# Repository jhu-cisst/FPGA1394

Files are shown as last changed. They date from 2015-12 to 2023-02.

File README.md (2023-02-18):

# FPGA1394
Design files for FPGA1394 board (FPGA + FireWire), Rev 1.x and 2.x, in Altium Designer format.
The design files for Rev 3.x are in [this repository](https://github.com/jhu-cisst/FPGA1394V3).

* `FPGA.PrjPCB`: Altium Designer project file
* `Snn.SchDoc`: schematics (Altium Designer format)
* `FPGA.PcbDoc`: PCB layout (Altium Designer format)
* `FPGA-Schematics.pdf`: PDF of schematics
* `FPGA-BOM.xls`: Bill of Materials (Microsoft Excel format)
* `FPGA1394-PCB-Fabrication.zip`: PCB fabrication (Gerber) files
* `FPGA1394-Assembly.zip`: PCB assembly files (e.g., paste masks, pick-and-place)
 
## Release Notes
 
* Rev 1.0/1.1 (PCB silkscreen is 1.0): Build #0 (5 board pilot run), Build #1 (44 boards)
* Rev 1.2: Build #2 (68 boards), Build #3 (72 boards)
  * Added J10 jumper on power input from IEEE-1394 (jumper OFF -> no power from IEEE-1394)
  * Changed J9 from 4-pin 2 mm header to 5-pin 0.1" header; pin 5 is connected to GND
  * Did not populate U12 (29.4989 MHz oscillator); use FPGA PLL to generate this frequency
* Rev 1.3: Build #4 (80 boards)
  * Added protection diodes (D10-D17), shunt regulator (U12), and supporting components to FireWire signal lines
  * Enable off-board 5V and 3.3V power (via U4 and U5) after local 5V power is good (determined by U9)
  * Added holes/pads on PCB traces for 5V, 3.3V, and 1.2V power supplies to facilitate troubleshooting
  * Removed 29.4989 MHz oscillator (U12) and supporting components from PCB and BOM (was "Do Not Install")
  * Modified U2 footprint to accommodate all variants of SO-8 package
  * Changed internal layers from 2 oz to 1 oz copper
* Rev 2.0: Prototype build (3 boards)
  * Added 10BASE-T/100BASE-TX Ethernet port using Micrel KSZ8851-16MLL MAC/PHY chip.
  * Redesigned DC/DC power supplies (5V, 3.3V, and 1.2V) to provide higher output currents.
  * Removed USB Mini connector (J6) and associated USB to UART bridge chip (CP2103). It is still possible to obtain a USB interface by connecting an appropriate TTL to USB Serial Converter Cable to header J9.
  * Removed jumper (J10) that allowed board to obtain power from IEEE-1394 cable (this feature was never used). Also removed power passthrough between IEEE-1394 connectors.
  * Removed diode isolation between power supply connectors J5 and J7; power should be connected to only one of these.
  * Changed FPGA oscillator from 40 MHz (pin AB12) to 25 MHz (pin M3).
  * Changes to the I/O pin connections on the FPGA (see schematic).
* Rev 2.1: Build #5 (92 boards), Build #6 (75 boards), Build #7 (120 boards), Build #8 (80 boards)
  * Moved power connector (J5) to increase space for JTAG connector (J8).
  * Corrected connection of "ST" and "FPGA PROG" LEDs (were swapped in Rev 2.0).
  * Fixed one unconnected GND test point, moved voltage test points, and added one more GND test point.
  * Changes to facilitate board assembly: wider slot spacing for IEEE-1394 connector, notch on board edge for better seating of IEEE-1394 connector, changed pad size for L1-L3.
* Rev 3.x: See [this repository](https://github.com/jhu-cisst/FPGA1394V3)

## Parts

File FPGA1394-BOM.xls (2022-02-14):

 | IEEE-1394/Ethernet FPGA Board, Rev 2.1
 | Bill Of Materials
 | 2022-02-14
Revision: |  | 2.1
Seq | Qty. | Ref Des | Description | Package | Manufacturer | Notes | Manufacturer Part # | Distributor | Distributor Part # | Avcon Part # | Est. Unit $ | Extended Cost
1 | 3 | C1-3 | CAP 10pF, 5%, 50V, NPO, 0603 | 0603 | MuRata | 2 | GRM1885C1H100JA01D | Digikey | 490-1403-1-ND | 022-1006-61/603 | 0.04 | 0.12
2 | 2 | C4-5 | CAP, 220pF, 5%, 50V, NPO, 0603 | 0603 | Kemet | 2 | C0603C221J5GACTU | Digikey | 399-1066-1-ND | 022-2216-61/603 | 0.02 | 0.05
3 | 1 | C6 | CAP, 1000pF, 5%, 50V, NPO, 0603 | 0603 | MuRata | 2 | GRM1885C1H102JA01D | Digikey | 490-1451-1-ND | 022-1026-61/603 | 0.03 | 0.03
4 | 3 | C7-9 | CAP 0.01uF, 10%, 50V, X7R, 0603 | 0603 | Kemet | 2 | C0603C103K5RACTU | Digikey | 399-1091-1-ND | 022-1036-71/603 | 0.04 | 0.13
5 | 4 | C10-13 | CAP, 0.1uF, 10%, 50V, X7R, 0603 | 0603 | MuRata | 2 | GCM188R71H104KA57D | Digikey | 490-4779-1-ND | 022-1046-71/603 | 0.04 | 0.14
6 | 5 | C14-18 | CAP, 1.0uF 10% 16V X7R, 0603 | 0603 | MuRata | 2, 8 | GRM188R71C105KA12D | Digikey | 490-3900-1-ND | 022-1052-71/603 | 0.05 | 0.24
7 | 5 | C19-23 | CAP, 10uF, 20%, 6.3V, X5R, 0603 | 0603 | MuRata | 2 | GRM188R60J106ME47D | Digikey | 490-3896-1-ND | 022-1060-81/603 | 0.01 | 0.03
8 | 2 | C24-25 | CAP, 10uF, 20%, 25V, X5R, 0805 | 0805 | MuRata | 2 | GRM21BR61E106KA73L | Digikey | 490-5523-1-ND | 022-1064-71/805 | 0.10 | 0.20
9 | 4 | C26-29 | CAP, 100uF, 20%, 10V, X5R, 1210 | 1210 | Samsung | 2 | CL32A107MPVNNNE | Digikey | 1276-3364-1-ND | 022-1071-81/121 | 0.65 | 2.60
10 | 2 | C30-31 | CAP, 220uF, 20%, 6.3V, X5R, 1210 | 1210 | Samsung | 2 | CL32A227MQVNNNE | Digikey | 1276-3375-1-ND | 022-2270-81/121 | 1.22 | 2.44
11 | 2 | C32-33 | CAP, 680uF 20%, 2.5V, Conductive Polymer "KO Cap" | CAP-D | Kemet | NS | T520D687M2R5ATE015 | Digikey | 399-4065-1-ND | 022-6870-81SMD | 1.31 | 2.62
12 | 2 | C34-35 | CAP, 470uF 20%, 6.3V, Conductive Polymer "KO Cap" | CAP-D | Kemet | NS, 9 | T520D477M006ATE025 | Digikey | 399-4985-1-ND | 022-4770-71SMD | 3.90 | 7.80
13 | 3 | C36-38 | CAP, 330uF 20%, 10V, Conductive Polymer "KO Cap" | CAP-D | Kemet | NS | T520Y337M010ATE015 (x=T or H) | Digikey | 399-10362-1-ND | 022-3371-81SM | 2.29 | 6.87
14 | 3 | C39-41 | CAP, 33uF 20%, 50V, Conductive Polymer "KO Cap" | CAP-D | Kemet | NS | T521X336M050ATE075 | Digikey | 399-11721-1-ND | 022-3366-81SM | 4.80 | 14.40
15 | 62 | C101-162 | CAP, 0.1uF, 10% 16V, X7R, 0402 | 0402 | MuRata | 2 | GRM155R71C104KA88D | Digikey | 490-3261-1-ND | 022-1042-71/402 | 0.00489 | 0.30
16 | 6 | CN1-6 | CAP Array, 4x 0.1uF, 10%, 16V, X7R | 0805 | AVX | 2, 6 | W2A4YC104KAT2A | Digikey | 478-11155-1-ND | 022-1040-81/805 | 0.28 | 1.69
17 | 1 | D1 | TVS, 28V, Unidirectional, 1500W, SMCJ28A | DIODE-SMC | Littlefuse | 2 | SMCJ28ALFCT-ND | Digikey | SMCJ28ALFCT-ND | 024-0949-SM | 0.46 | 0.46
18 | 1 | D2 | DIODE, Zener, 10V, MMSZ5240 | SOD-323 | Vishay |  | MMSZ5240BS-7-F | Digikey | MMSZ5240BS-FDICT-ND | 024-0309-SM | 0.19 | 0.19
19 | 5 | D3-7 | LED, Green, RA, 0805 | 0805 | Osram |  | LG R971-KN-1 | Digikey | 475-1410-1-ND | 024-6176-805 | 0.06 | 0.30
20 | 8 | D8-15 | DIODE, BAV99T, Dual/Serial, 70V, 85mA | SOT-523 | Diodes Inc. |  | BAV99T-7-F | Digikey | BAV99T-FDICT-ND | 024-0118-SM | 0.04 | 0.34
21 | 2 | J1-2 | CONN, Socket, 2x22 Pos, Vertical, 2MM | TH | Samtec |  | ESQT-122-02-L-D-560 | Samtec | ESQT-122-02-L-D-560 | 026-0844-00 | 5.72 | 11.44
22 | 2 | J3-4 | CONN, IEEE-1394, 6-Pin, R/A | Firewire6-RA | 3M | NS, 10 | 3E106-2230KV | Digikey | 3M9423-ND | 026-1139-00 | 3.34 | 6.69
23 | 1 | J5 | CONN, Power Jack, 2.1mm, RA | TH | Switchcraft | 2 | RAPC722X | Digikey | SC1313-ND | 026-0383-00 | 0.87 | 0.87
24 | 1 | J6 | CONN, RJ-45 with Ethernet Transformer | RJ-45 | Pulse |  | J00-0045NL | Digikey | 553-1619-5-ND | 026-0690-00 | 4.49 | 4.49
25 | 1 | J7 | CONN, Header, 2 Pos, Vertical 0.100 | TH | Tyco | 2 | 640456-2 | Digikey | A1921-ND | 026-0080-00 | 0.09 | 0.09
26 | 1 | J8 | CONN, Header, 2x7 Pos, Vertical, Polarized, 2MM | TH | FCI |  | 98414-G06-14LF | Digikey | 609-2576-ND | 026-0847-00 | 1.74 | 1.74
27 | 1 | J9 | CONN, Header, 6 Pos, Vert 0.1" pitch, 0.23" - 0.318" ht | TH | Generic | 2 | 5-146280-6, TSW-106-07-L-S | Digikey | A121372-ND | 029-0507-06 | 0.45 | 0.45
28 | 1 | L1 | INDUCTOR, 4.7uH, 15A, XAL7070 | XAL7070 | Coilcraft | NS | XAL7070-472MEx (x=B or C) | Coilcraft | XAL7070-472MEB | 023-0381-SM | 3.14 | 3.14
29 | 2 | L2-3 | INDUCTOR, 3.3uH, 5.5A, XAL4030 | XAL4030 | Coilcraft | NS | XAL4030-332MEx (x=B or C) | Coilcraft | XAL4030-332MEB | 023-0372-SM | 1.80 | 3.60
30 | 3 | L4-6 | FERRITE BEAD, 50 Ohm/10 mOhm, 6A | 1206 | Laird | 2 | HI1206T500R-10 | Digikey | 240-2412-1-ND | 023-0431-1206 | 0.06 | 0.17
31 | 4 | L7-10 | INDUCTOR, 1uH, 600mA, 200mOhm | 0603 | Kemet | 2 | L0603B1R0MPWFT | Digikey | 399-9562-1-ND | 023-0432-603 | 0.22 | 0.87
32 | 2 | Q1-2 | MOSFET, N-Chan, 20V, Si7108 | PowerPack-1212 | Vishay |  | SI7108DN-T1-GE3 | Digikey | SI7108DN-T1-GE3CT-ND | 024-2189-SM | 1.31 | 2.62
33 | 1 | Q3 | MOSFET, P-Chan, 40V, Si7611 | PowerPack-1212 | Vishay | 4 | SI7611DN-T1-GE3 | Digikey | SI7611DN-T1-GE3CT-ND | 024-2193-SM | 0.70 | 0.70
34 | 3 | Q4-6 | MOSFET, Dual N-Chan, 30V, PMGD175XN | SOT-363 | ON Semi | 2, 7 | NTJD4001NT1G | Digikey | NTJD4001NT1GOSCT-ND | 024-2190-SM | 0.43 | 1.29
35 | 1 | Q7 | TRANSISTOR, PNP, 1A, 20V, DCX69-16 | SOT-89 | NXP | 5 | BC869-16,115 | Digikey | 1727-2363-1-ND | 024-1036-SM | 0.35 | 0.35
36 | 8 | R1-8 | RES, 56.0, 0.5%, 1/10W, 0603 | 0603 | Susumu | 2 | RR0816Q-560-D | Digikey | RR08Q56DCT-ND | 020-5607-41/603 | 0.02 | 0.19
37 | 4 | R9-12 | RES, 4.99K, 1%, 1/10W, 0603 | 0603 | Generic | 2 | ERJ-3EKF4991V |  |  | 020-4991-51/603 | 0.03 | 0.10
38 | 1 | R13 | RES, 6.34K, 1%, 1/10W, 0603 | 0603 | Generic | 2 | RC0603FR-076K34L |  |  | 020-6341-51/603 | 0.02 | 0.02
39 | 5 | R14-18 | RES, 499, 1%, 1/10W, 0603 | 0603 | Generic | 2 | CRCW0603499RDHEAP (0.5%) |  |  | 020-4990-51/603 | 0.09 | 0.45
40 | 2 | R19-20 | RES, 100, 1%, 1/10W, 0603 | 0603 | Generic | 2 | RK73H1JTTD1000F |  |  | 020-1000-51/603 | 0.01 | 0.02
41 | 2 | R21-22 | RES, 200, 1%, 1/10W, 0603 | 0603 | Generic | 2 | RMCF0603FT200R |  |  | 020-2000-51/603 | 0.01 | 0.01
42 | 2 | R23-24 | RES, 1.00K, 1%, 1/10W, 0603 | 0603 | Generic | 2 | RC0603FR-071KL |  |  | 020-1001-51/603 | 0.01 | 0.02
43 | 1 | R25 | RES, 20.0K, 1%, 1/10W, 0603 | 0603 | Generic | 2 | RC0603FR-0720KL |  |  | 020-2002-51/603 | 0.02 | 0.02
44 | 1 | R26 | RES, 31.6K, 1%, 1/10W, 0603 | 0603 | Generic | 2 | ERJ-3EKF3162V |  |  | 020-3162-51/603 | 0.03 | 0.03
45 | 2 | R27-28 | RES, 49.9K, 1%, 1/10W, 0603 | 0603 | Generic | 2 | CRCW060349K9FKEA |  |  | 020-4992-51/603 | 0.06 | 0.11
46 | 1 | R29 | RES, 3.01K, 1%, 1/10W, 0603 | 0603 | Generic | 2 | CRCW06033K01FKEA |  |  | 020-3011-51/603 | 0.04 | 0.04
47 | 3 | R30-32 | RES, 15.0K, 1%, 1/10W, 0603 | 0603 | Generic | 2 | RC0603FR-0715KL |  |  | 020-1502-51/603 | 0.01 | 0.03
48 | 4 | R33-36 | RES, 133K, 1%, 1/10W, 0603 | 0603 | Generic | 2 | ERJ-3EKF1333V |  |  | 020-1333-51/603 | 0.002 | 0.01
49 | 2 | R37-38 | RES, 66.5K, 1%, 1/10W, 0603 | 0603 | Generic | 2 | ERJ-3EKF6652V |  |  | 020-6652-51/603 | 0.01 | 0.03
50 | 1 | R39 | RES, 69.8K, 1%, 1/10W, 0603 | 0603 | Generic | 2 | ERJ-3EKF6982V |  |  | 020-6982-51/603 | 0.03 | 0.03
51 | 5 | R40-44 | RES, 301K, 0.1%, 1/10W, 0603 | 0603 | Susumu | 2 | RG1608P-3013-B-T5 | Digikey | RG16P301KBCT-ND | 020-3013-21/603 | 0.14 | 0.69
52 | 1 | R45 | Do Not Install | 0603 | Generic |  |  |  |  |  |  | 0.00
53 | 6 | R46-51 | RES, 49.9, 1%, 1/16W, 0402 | 0402 | Generic | 2 | RC0402FR-0749R9L |  |  | 020-4999-51/402 | 0.01 | 0.04
54 | 1 | R52 | RES, 0.050, 1%, 1/2W, 1206 | 1206 | Stackpole | 2 | CSR1206FK50L0 | Digikey | CSR1206FK50L0CT-ND | 020-5007-54SM | 0.23 | 0.23
55 | 1 | R53 | RES, 0.025, 1%, 1/2W, 1206 | 1206 | Stackpole | 2 | CSR1206FK25L0 | Digikey | CSR1206FK25L0CT-ND | 020-2507-54SM | 0.23 | 0.23
56 | 5 | RN1-5 | RES ARRAY, 4.7K, 4 DIS, 5%, SM 0.032 | R-SM-8/32 | CTS | 2 | 742C083472JP | Digikey | 742C083472JPCT-ND | 020-4701-61RA | 0.06 | 0.30
57 | 1 | RN6 | RES ARRAY, 220, 4 DIS, 5%, SM 0.032 | R-SM-8/32 | CTS | 2 | 742C083221JP | Digikey | 742C083221JPCT-ND | 020-2200-61RASM | 0.23 | 0.23
58 | 1 | SW1 | SWITCH, Rotary, Hex | TH | Grayhill | 2 | 94HAB16T | Digikey | GH7255-ND | 029-0458-00 | 2.48 | 2.48
59 | 1 | U1 | IC, FPGA, Spartan 6, XC6SLX45-FG484 | FG-484 | Xilinx | NS | XC6SLX45-2FGG484C | Digikey | 122-1674-ND | 024-9308-SM | 29.25 | 29.25
60 | 1 | U2 | IC, Serial Flash PROM, 16MBit, M25P16 | SO-8 | Numonyx |  | M25P16-VMN6P | Digikey | M25P16-VMN6P-ND | 024-4182-SM | 1.15 | 1.15
61 | 1 | U3 | IC, IEEE-1394 Physical Layer, TSB41AB2 | PQFP-65 | TI | NS | TSB41AB2PAP | Digikey | 296-11076-ND | 024-9309-SM | 5.55 | 5.55
62 | 1 | U4 | IC, Ethernet MAC/PHY Controller, KSZ8851 | QFP-48-7MM | Micrel | NS | KSZ8851-16MLL | Digikey | 576-3252-ND | 024-2751-SM | 4.28 | 4.28
63 | 2 | U5-6 | IC, MEMS Oscillator, 25.0 MHz | OSC-2x2.5mm | ECS, Inc. | 3 | ECS-2520MVQ-250-BP-TR | Digikey | 50-ECS-2520MVQ-250-BP-CT-ND | 024-9372-SM | 1.11 | 2.22
64 | 1 | U7 | IC, Oscillator, 24.576MHz, 50PPM, 3.3V | OSC-3x5MM | AVX | 2 | KC5032A24.5760CMxE00 | Digikey | 1253-1042-1-ND | 029-0459-SM | 1.31 | 1.31
65 | 2 | U8-9 | IC, Hot Swap Controller with retry, LTC4210-1 | SOT-23-6 | Linear Tech | 1 | LTC4210-1CS6#PBF | Linear Tech | LTC4210-1CS6#PBF | 024-3782-SM | 3.39 | 6.78
66 | 1 | U10 | IC, Step Down DC-DC, 42V, 6A, LT8612 | QFN-28-3x6mm | Linear Tech | 1 | LT8612EUDE#PBF | Linear Tech | LT8612EUDE#PBF | 024-2752-SM | 8.40 | 8.40
67 | 1 | U11 | IC, Dual DC-DC Converter, 3A/Chan, LTC3615 | QFN-24-4mm | Linear Tech | 1 | LTC3615EUF#PBF | Linear Tech | LTC3615EUF#PBF-ND | 024-2753-SM | 5.00 | 5.00
68 | 1 | U12 | IC, 4 Phase Spread Spectrum Clock, LTC6902 | MSOP-10 | Linear Tech | 1 | LTC6902CMS#TRPBFCT | Linear Tech | LTC6902CMS#TRPBF | 024-2754-SM | 4.28 | 4.28
69 | 1 | U13 | IC, Shunt Regulator, 1.24V, 70mA, TLVH431 | SC70-6 | TI |  | TLVH431ACDCK | Digikey | 296-32425-1 | 024-2415-SM | 0.68 | 0.68
70 | 1 |  | PCB, IEEE-1394/Ethernet FPGA Controller, Rev 2.1 |  |  |  |  |  |  |  | 7.60 | 7.60
 |  |  |  |  |  |  |  |  |  | Estimated Total Cost: |  | $161.27
Notes:
 | ● | Text highlighted in red is highlighted to draw attention to the value/parameter and does not carry any special meaning.
 | ● | Component prices shown are the best guess at the time of updating this BOM, assuming Qty ~100 boards. Actual prices may be higher or lower depending upon a number of factors.
 | ● | Unless specified otherwise, the only substitutions allowed are substituting identical part number parts from a different manufacturer.
 | NS | No substitutions of any kind are allowed.
 | 1 | For Linear Tech parts, it is acceptable to substitute I (industrial temp), E (extended temp) or H (high temp) rated parts.
 |  | The suffixes "TRM" and "TR" signify tape and reel styles. Parts with suffix TRM, suffix TR can be substituted as needed.
 |  | Other than as specified above, no other substitutions are allowed.
 | 2 | Any component in an identical package that meets or exceeds all the parameters specified in the description can be substituted.
 | 3 | Previously used Silicon Labs 501MAA-ADAG, which was ordered pre-programmed for 25.0MHz from Digikey, and then Abracon KC5032A24.5760CM0E00
 | 4 | An alternate part is SIS443DN (Digikey P/N SIS443DN-T1-GE3CT-ND)
 | 5 | Previously used DCX69-16-13 (Digikey P/N DCX69-16DICT-ND). Alternate part is higher-rated PNP 3A 25V (Digikey P/N FCX789ACT-ND)
 | 6 | Previously used TDK/Samsung CL21B104MOCNBNC (Digikey P/N 1276-2452-1-ND)
 | 7 | Previously used NXP PMGD175XNE (Digikey P/N 1727-2695-1-ND) and PMGD370XN (Digikey P/N 568-2367-1-ND). It is also possible to use NTJD4401NT1G, but note that it is a 20V part
 | 8 | It is acceptable to substitute an X5R capacitor, such as GRM188R61C105KA12D
 | 9 | Another approved part is Panasonic 6TPE470M
 | 10 | Another approved part is TE Connectivity AMP 5787956-1 (Digikey P/N A114040-ND)

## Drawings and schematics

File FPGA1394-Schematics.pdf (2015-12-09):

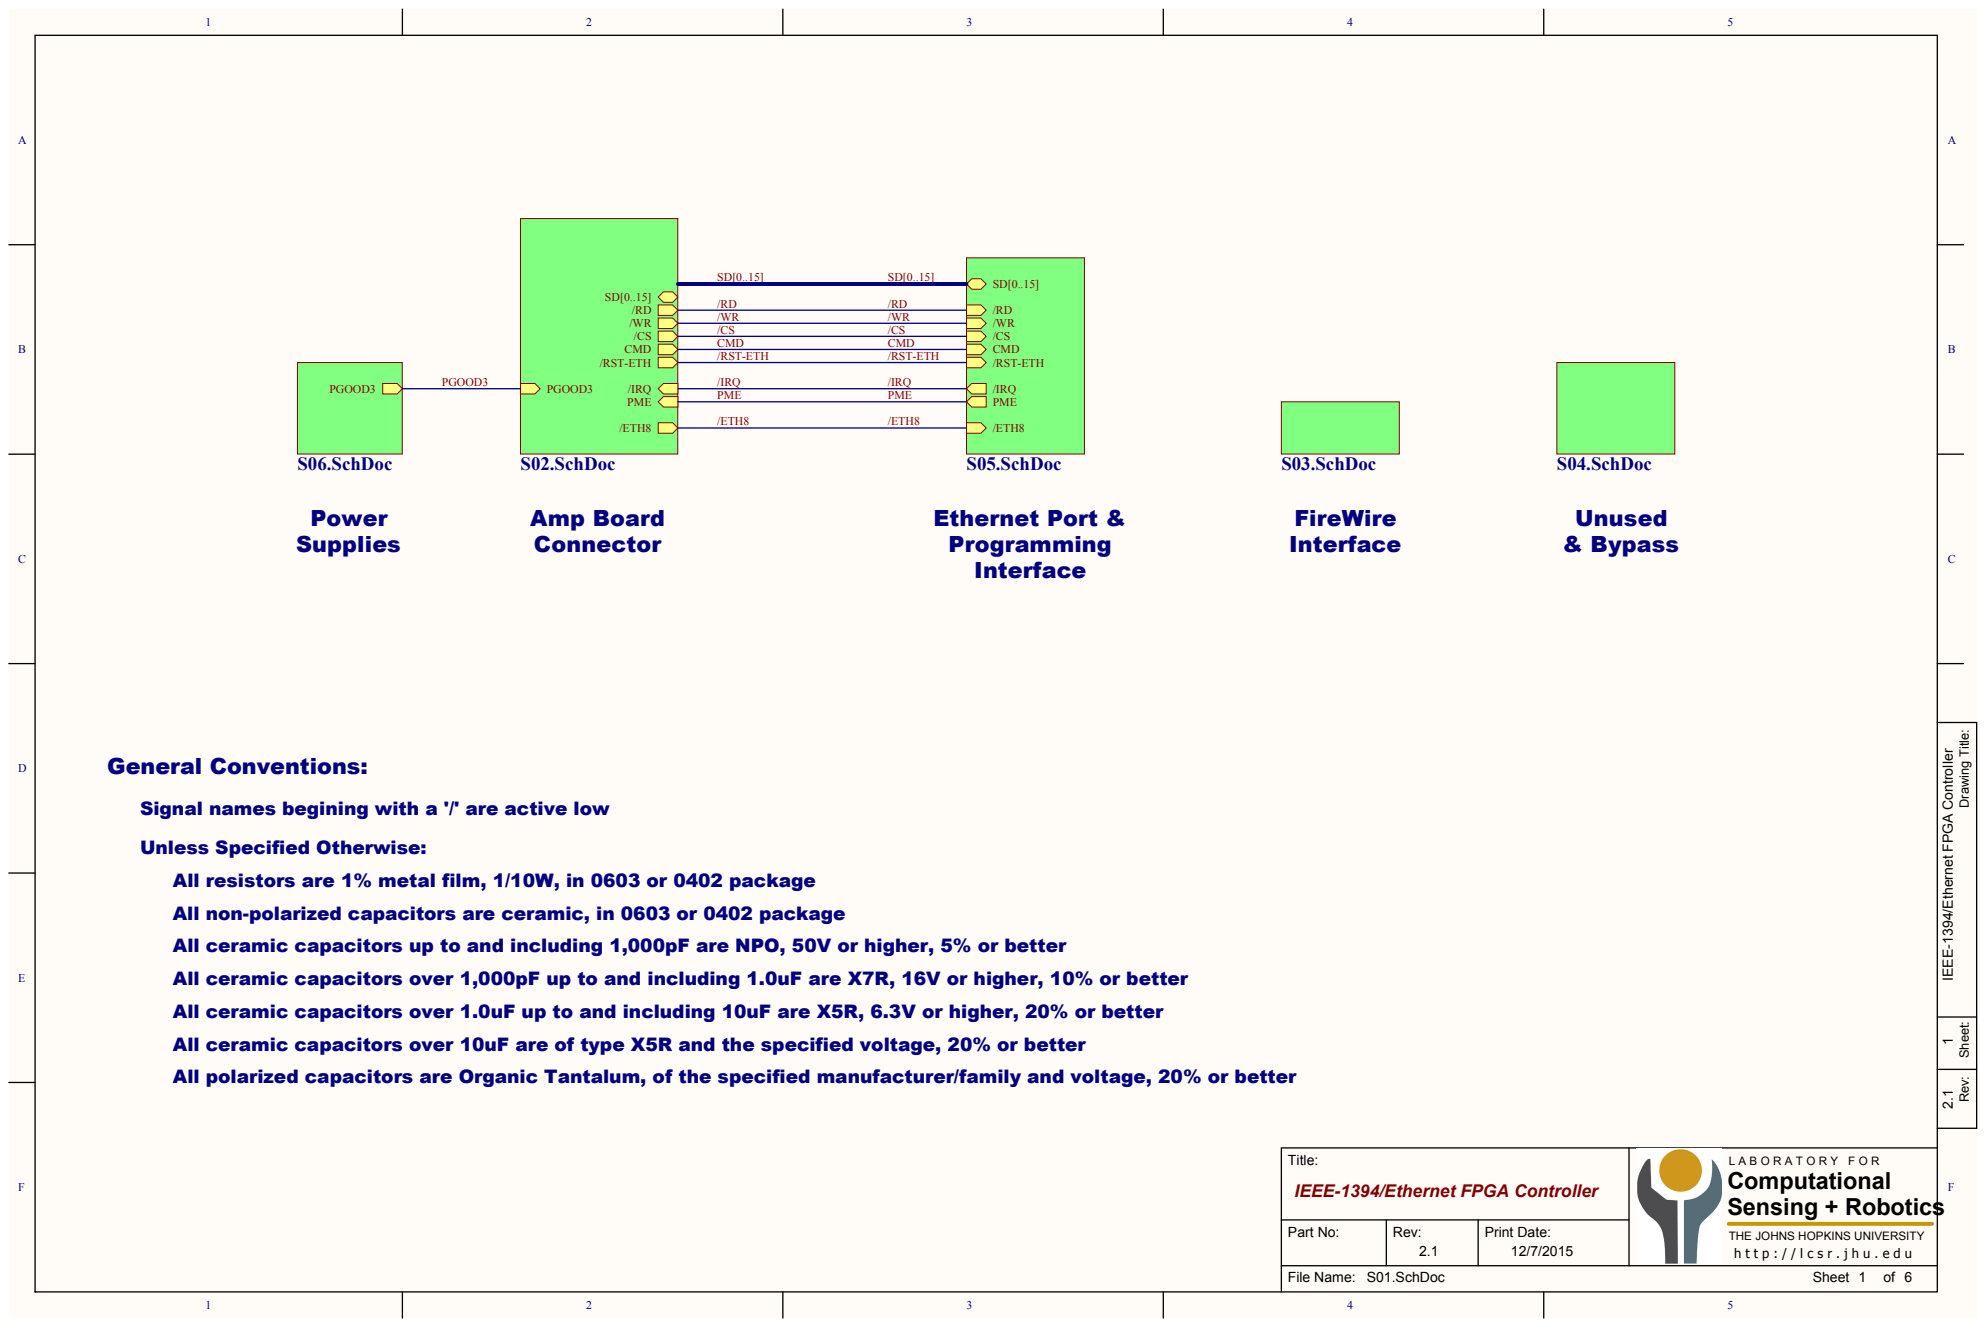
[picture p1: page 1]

Drawing Title: Rev: Sheet:

1 IEEE-1394/Ethernet FPGA Controller 2.1

Signal names begining with a '/' are active low

Unless Specified Otherwise:
All resistors are 1% metal film, 1/10W, in 0603 or 0402 package
All non-polarized capacitors are ceramic, in 0603 or 0402 package
All ceramic capacitors up to and including 1,000pF are NPO, 50V or higher, 5% or better
All ceramic capacitors over 1,000pF up to and including 1.0uF are X7R, 16V or higher, 10% or better
All ceramic capacitors over 1.0uF up to and including 10uF are X5R, 6.3V or higher, 20% or better
All ceramic capacitors over 10uF are of type X5R and the specified voltage, 20% or better
All polarized capacitors are Organic Tantalum, of the specified manufacturer/family and voltage, 20% or better

Title: IEEE-1394/Ethernet FPGA Controller | L A B O R A T O R Y F O R Computational THE JOHNS HOPKINS UNIVERSITY h t t p : / / l c s r . j h u . e d u

Part No: | Rev: 2.1 | Print Date: 12/7/2015

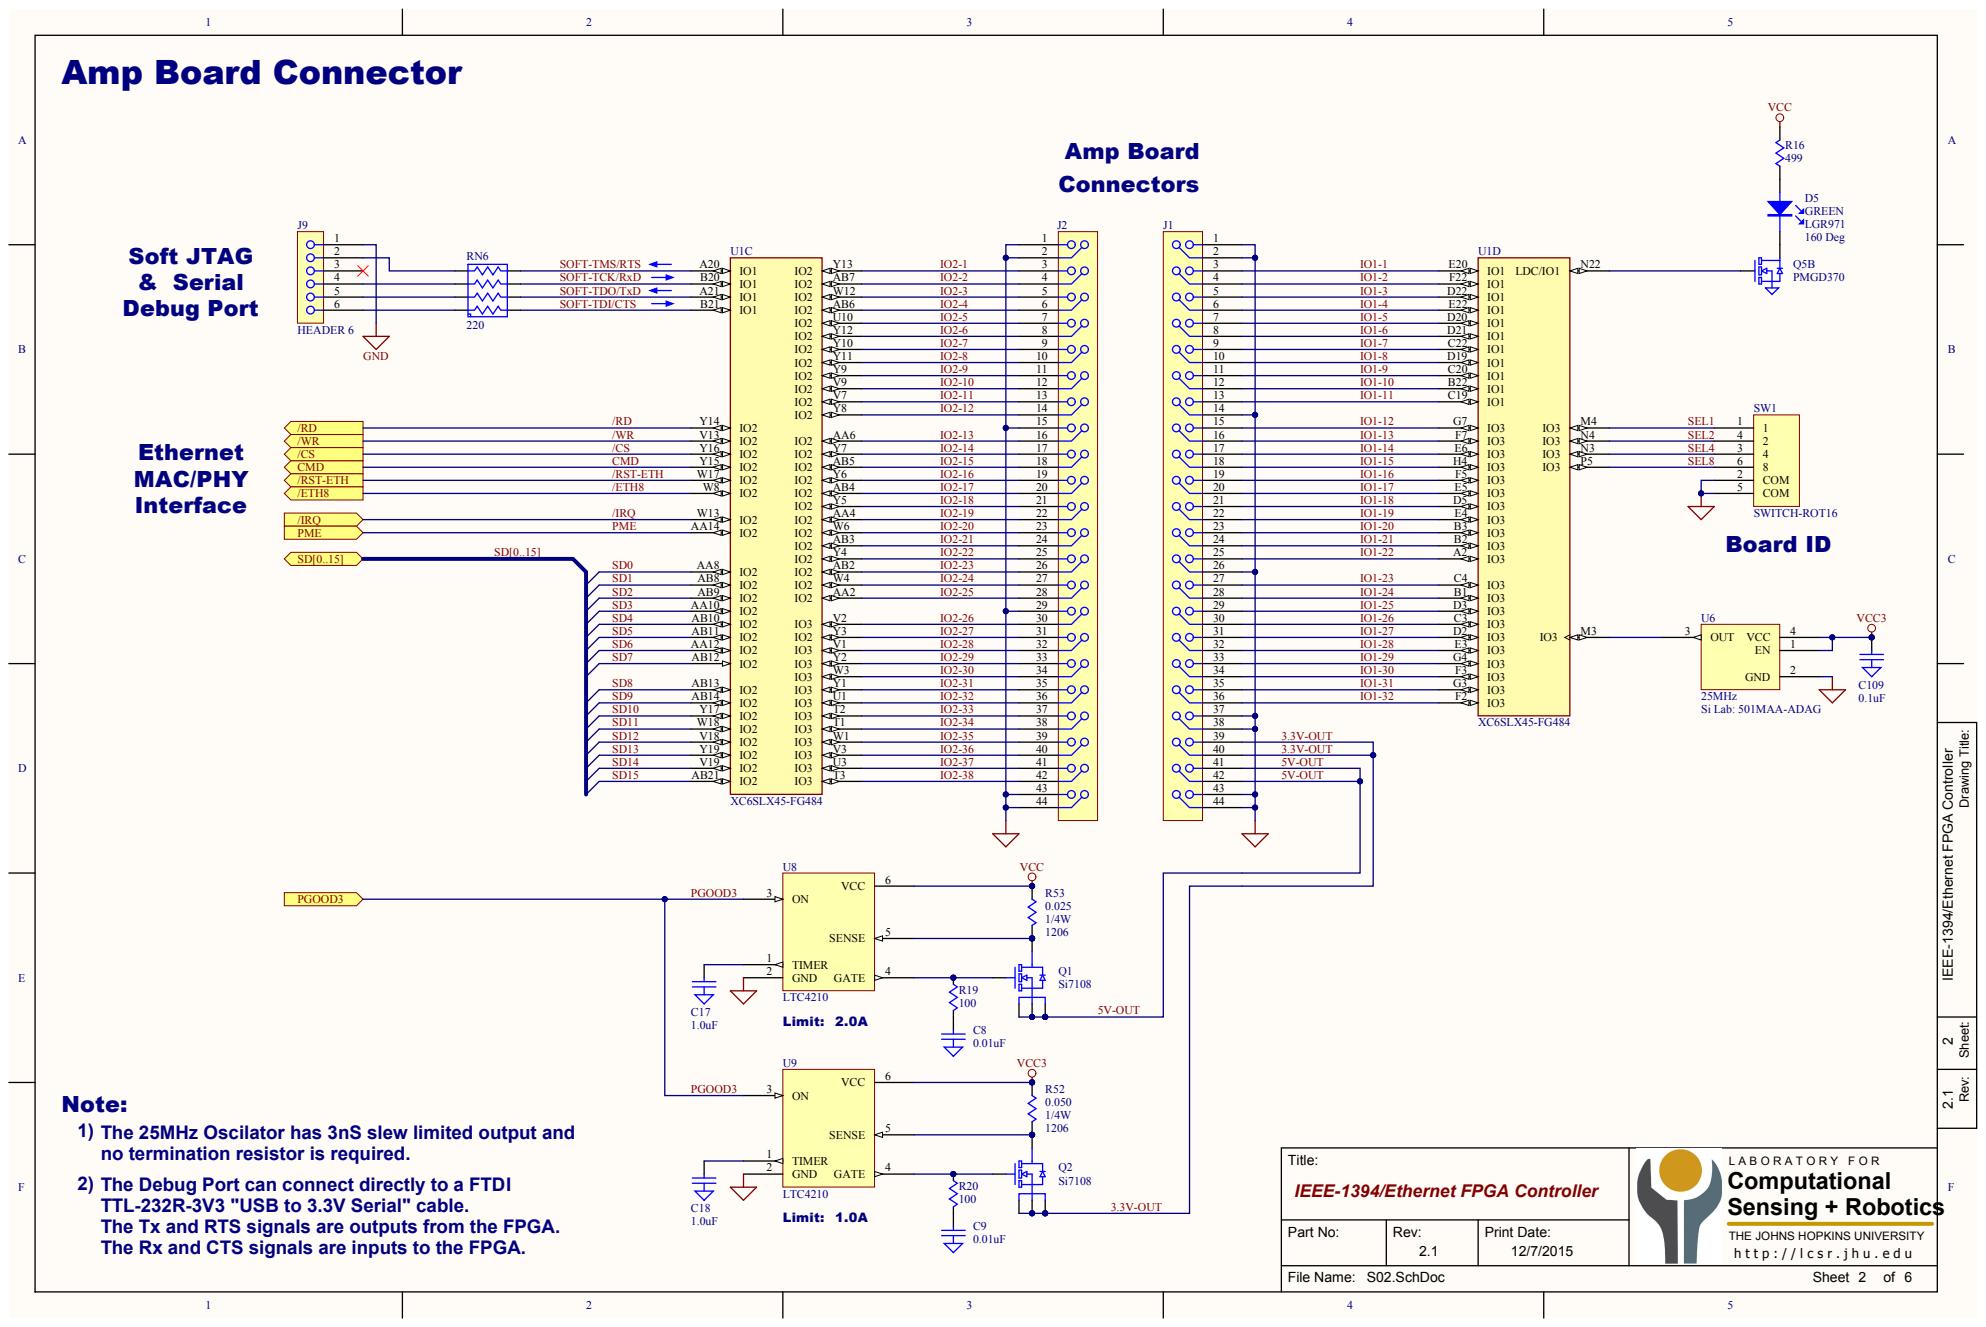
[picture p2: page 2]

Drawing Title: Rev: Sheet:

2 IEEE-1394/Ethernet FPGA Controller 2.1

Note: The 25MHz Oscilator has 3nS slew limited output and
no termination resistor is required.
The Debug Port can connect directly to a FTDI TTL-232R-3V3 "USB to 3.3V Serial" cable. The Tx and RTS signals are outputs from the FPGA

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

Part No: | Rev: 2.1 | Print Date: 12/7/2015

The Rx and CTS signals are inputs to the FPGA

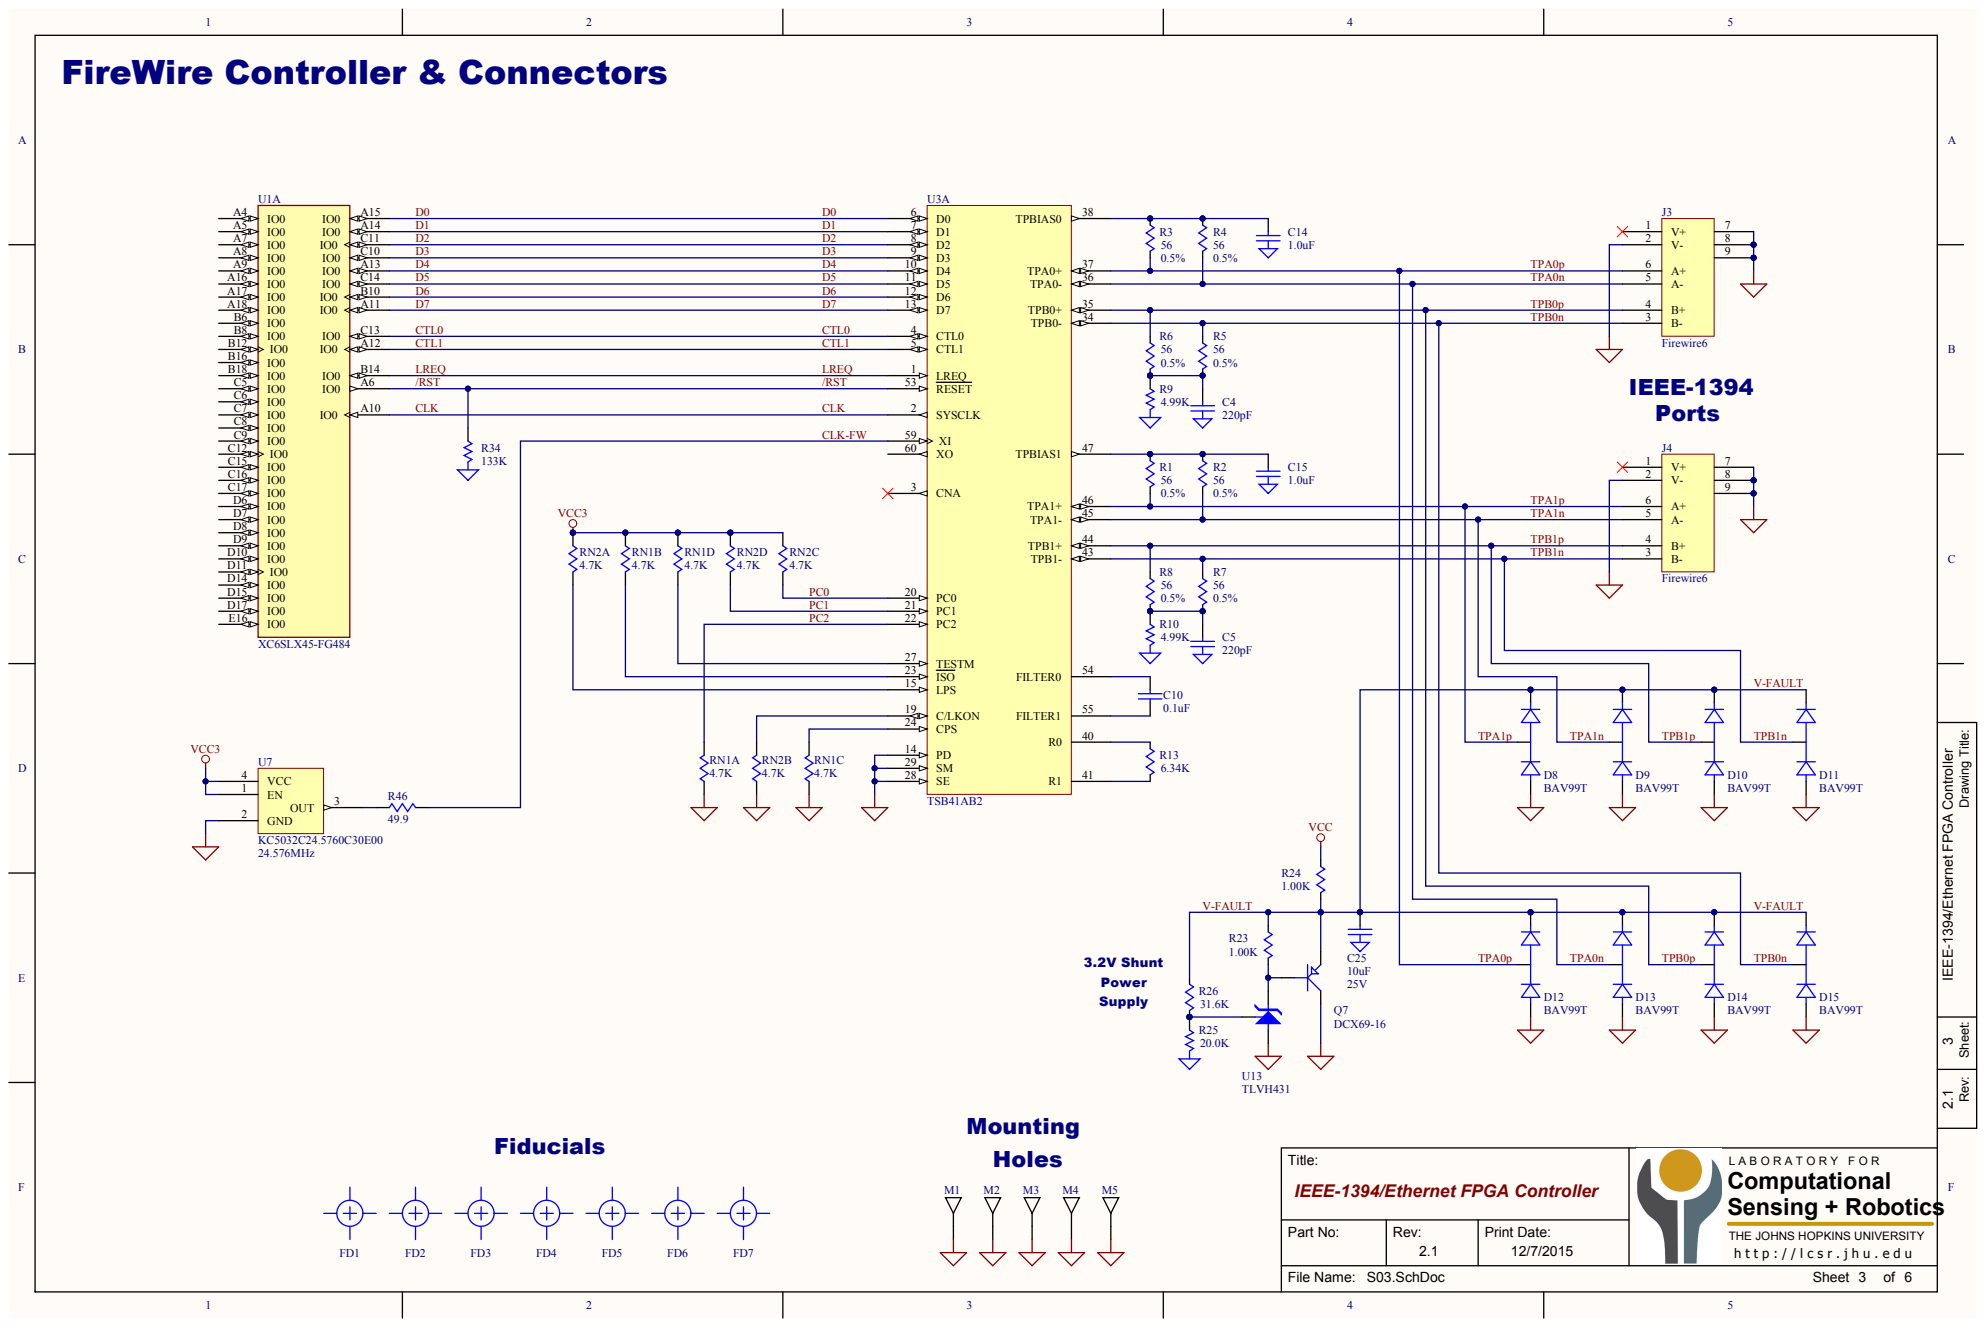
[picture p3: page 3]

IO0 C5 | /RST | RESET 53
IO0 C6 | CLK | CLK | SYSCLK 2

TESTM 27

LPS 15

Drawing Title: Rev: Sheet:

3 IEEE-1394/Ethernet FPGA Controller 2.1

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

Part No: | Rev: 2.1 | Print Date: 12/7/2015

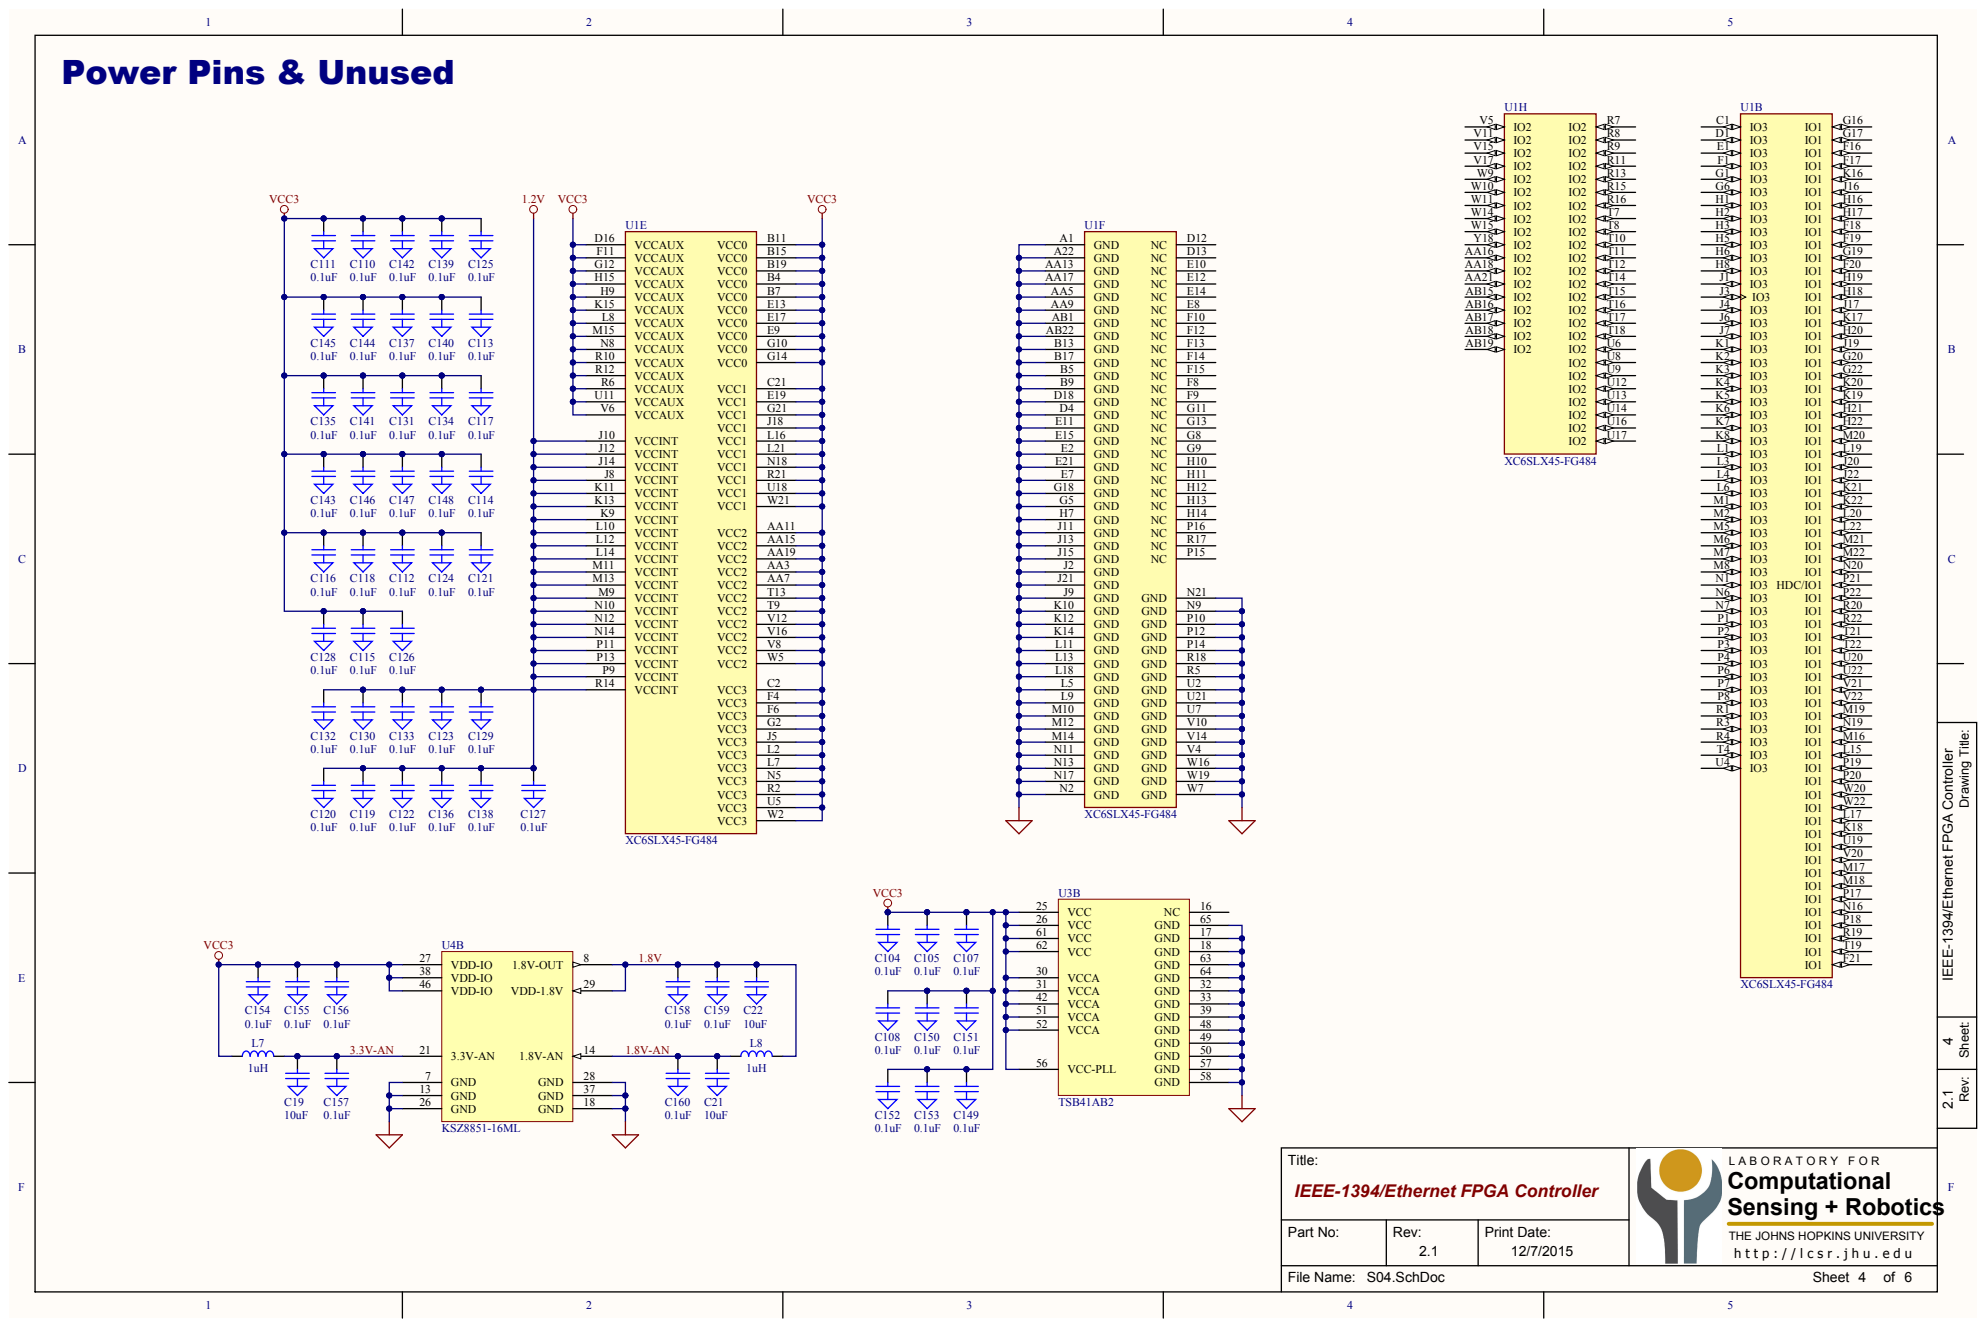
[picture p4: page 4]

Drawing Title: Rev: Sheet:

4 IEEE-1394/Ethernet FPGA Controller 2.1

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

Part No: | Rev: 2.1 | Print Date: 12/7/2015

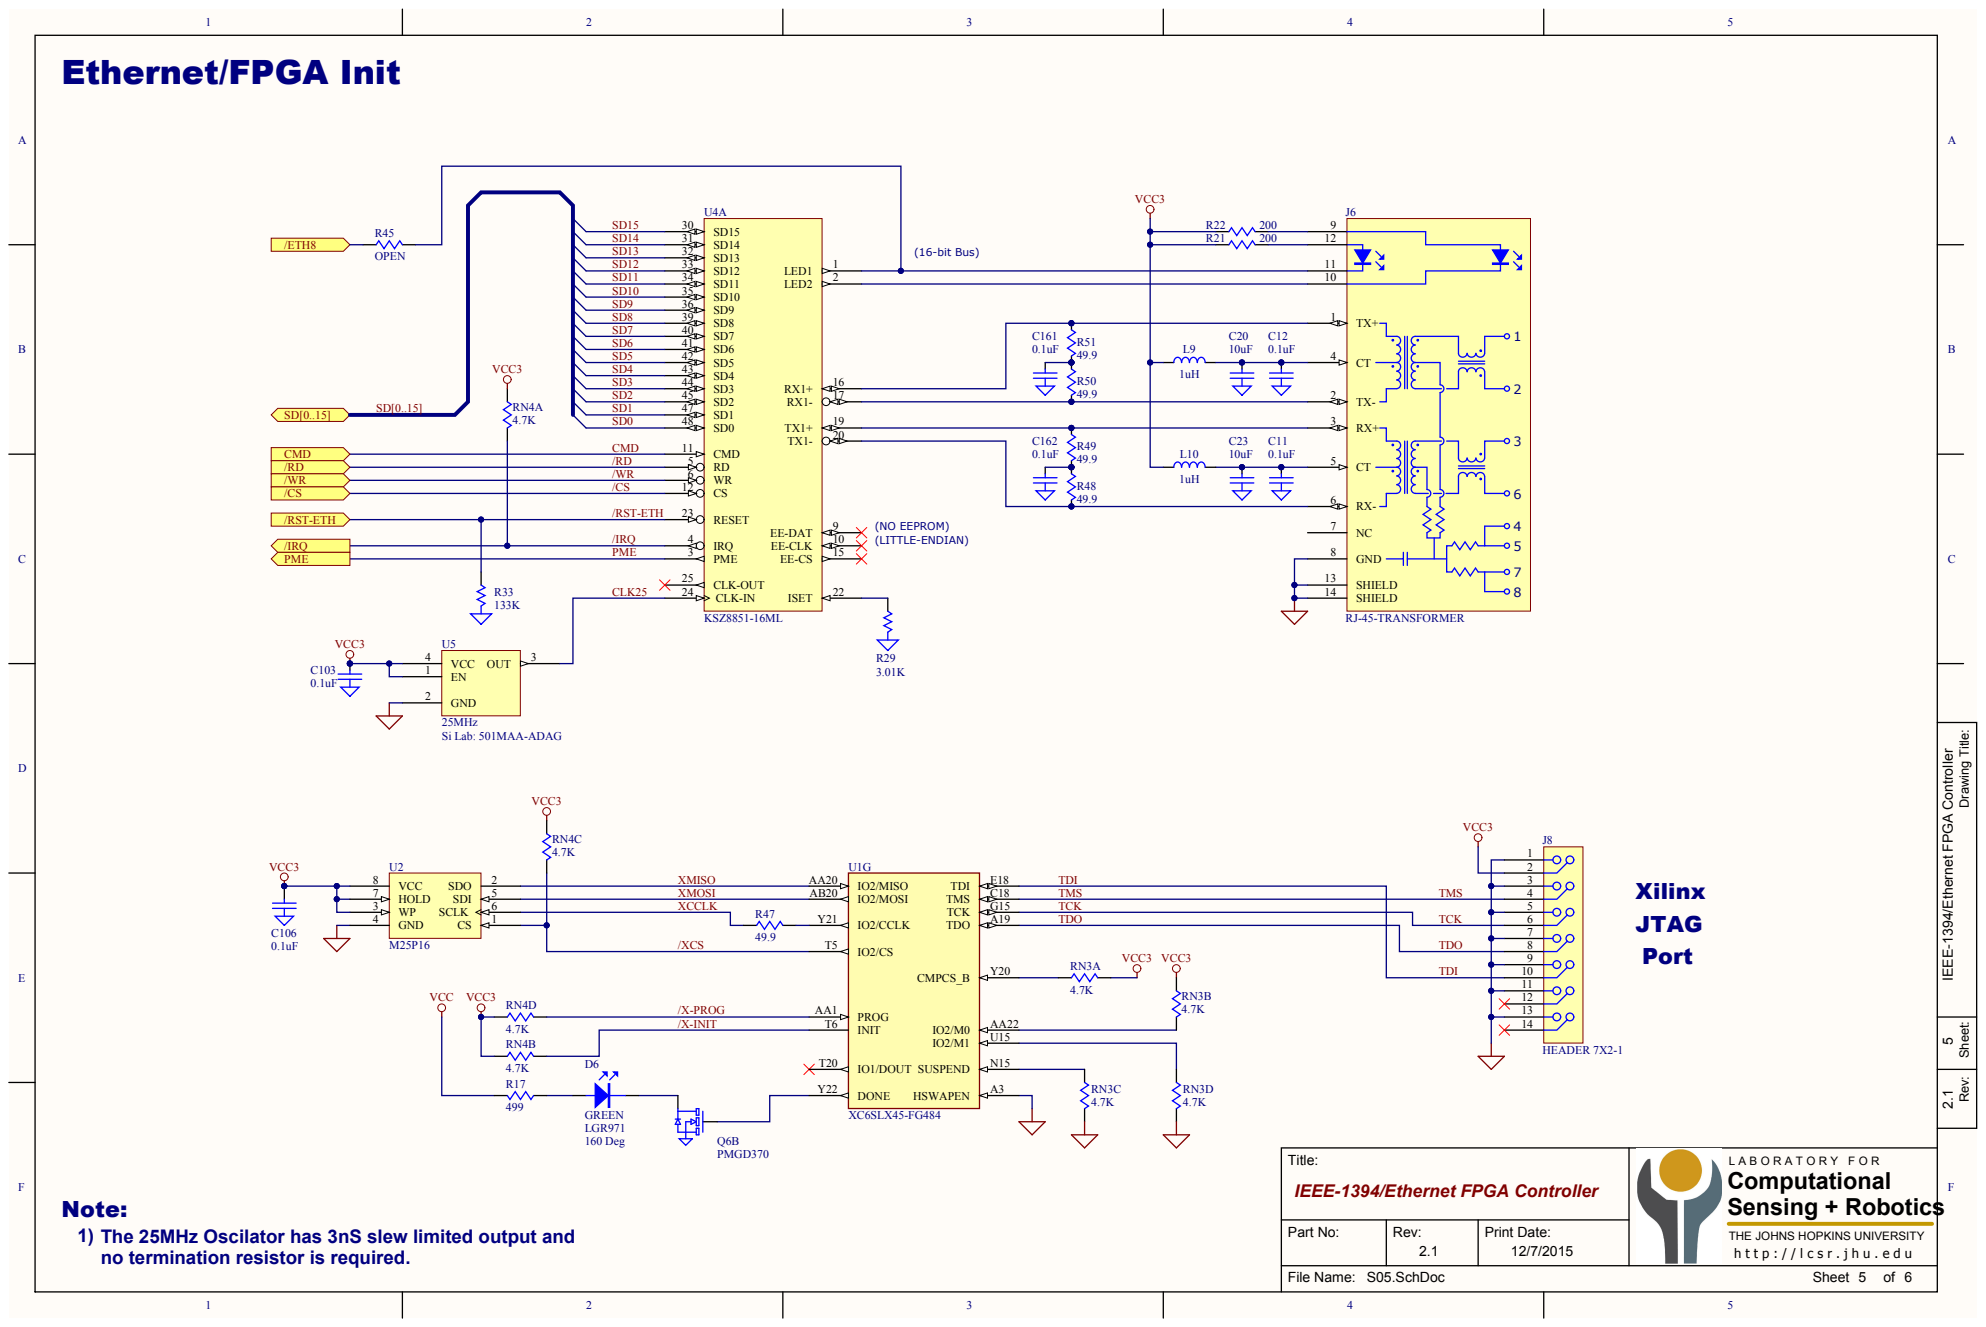
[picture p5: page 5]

Drawing Title: Rev: Sheet:

5 IEEE-1394/Ethernet FPGA Controller 2.1

10
11

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

Note:
The 25MHz Oscilator has 3nS slew limited output and
no termination resistor is required.

Part No: | Rev: 2.1 | Print Date: 12/7/2015

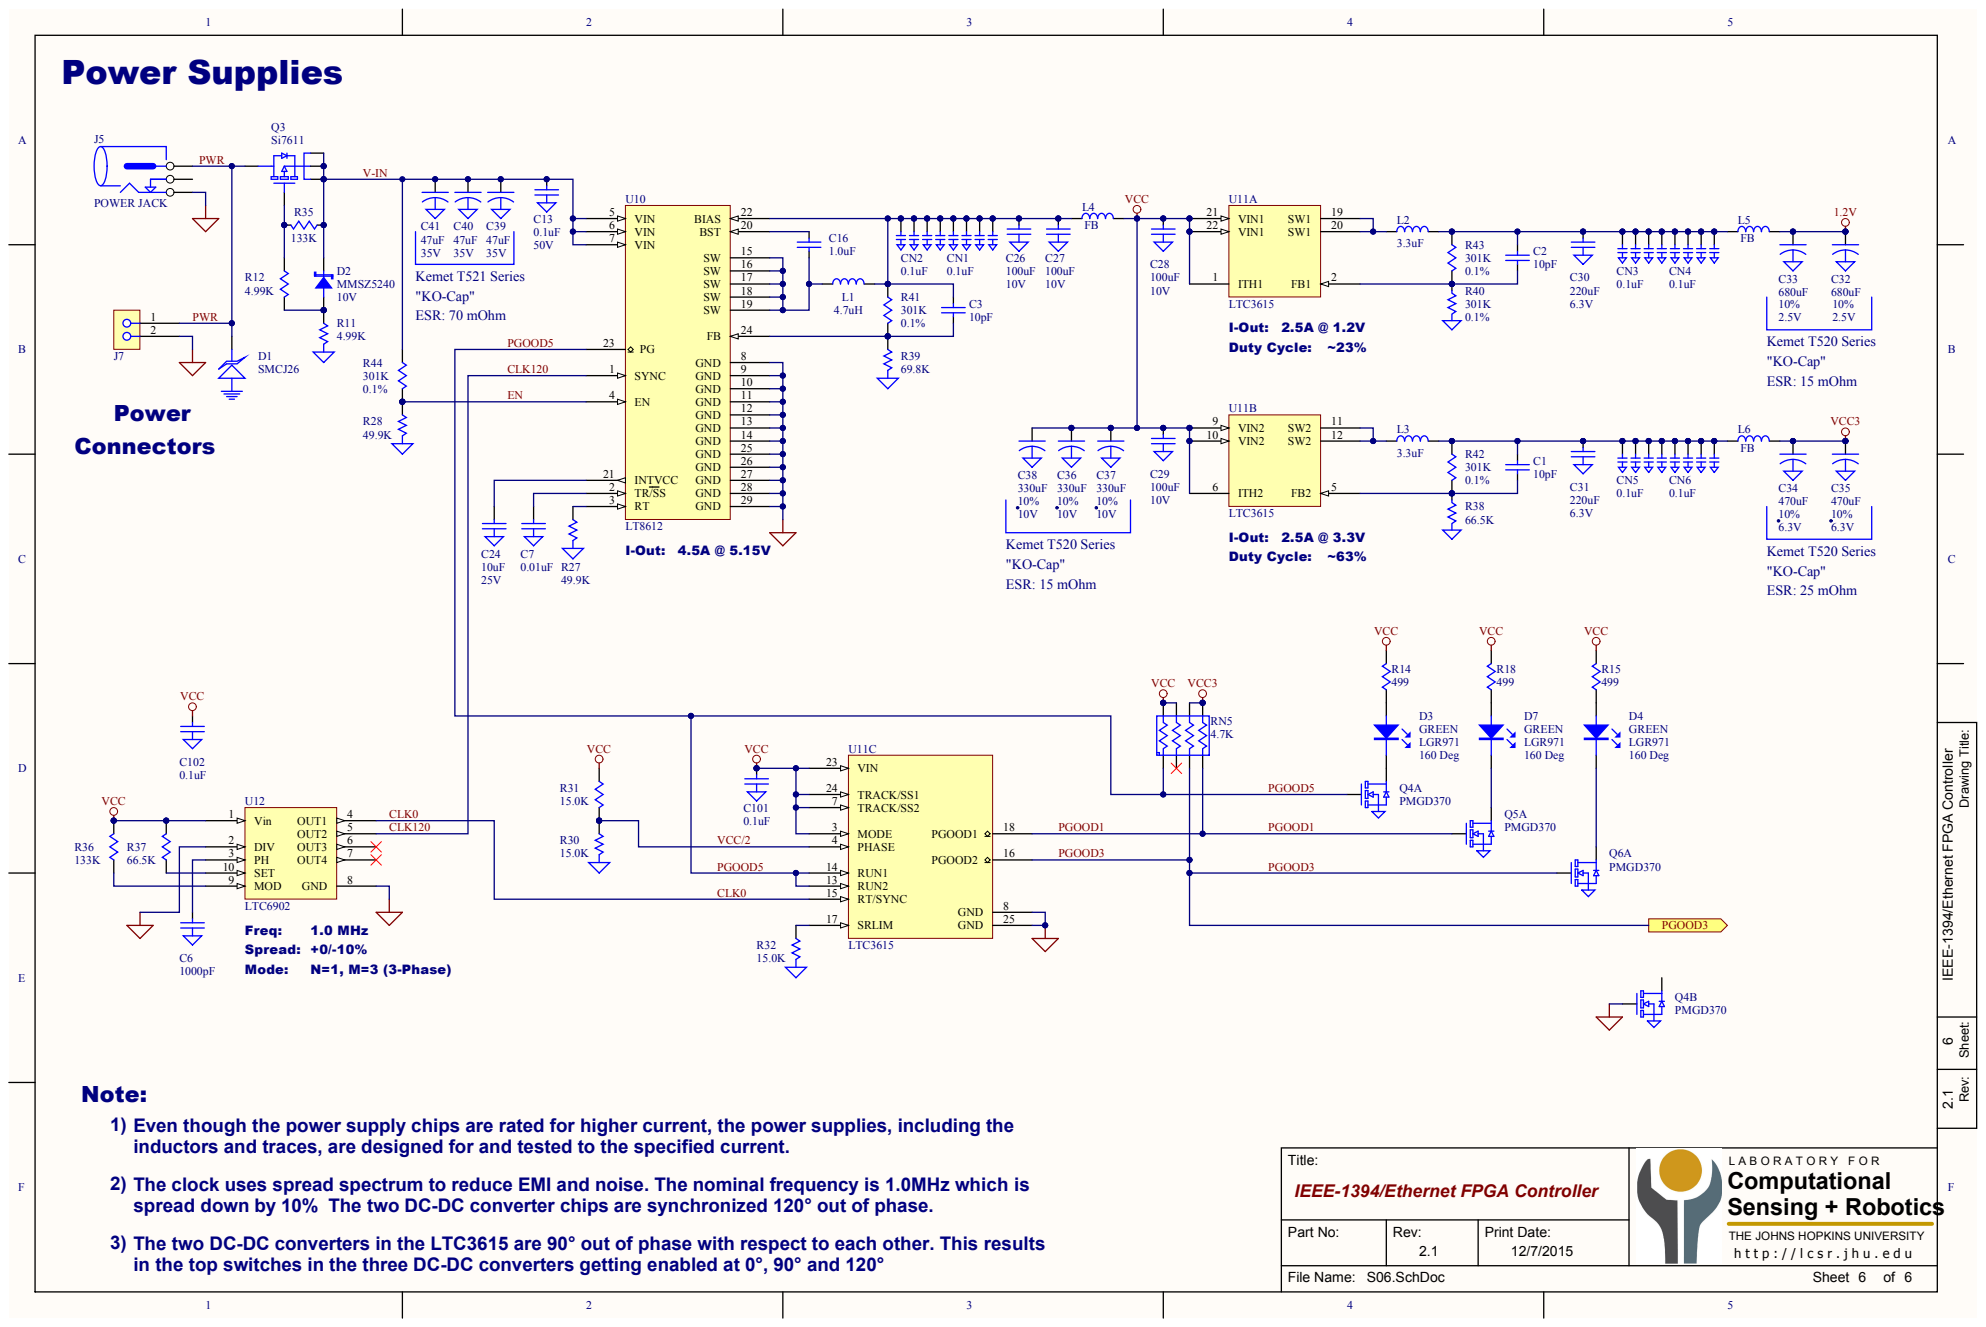
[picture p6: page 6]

Drawing Title: Rev: Sheet:

6 IEEE-1394/Ethernet FPGA Controller 2.1

PGOOD5 | RUN1 14

RUN2 13

Note:
Even though the power supply chips are rated for higher current, the power supplies, including the
inductors and traces, are designed for and tested to the specified current.

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

The clock uses spread spectrum to reduce EMI and noise. The nominal frequency is 1.0MHz which is
spread down by 10% The two DC-DC converter chips are synchronized 120° out of phase.

The two DC-DC converters in the LTC3615 are 90° out of phase with respect to each other. This results
in the top switches in the three DC-DC converters getting enabled at 0°, 90° and 120°

Part No: | Rev: 2.1 | Print Date: 12/7/2015

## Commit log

2015-01-19 Initial commit, Rev 1.0/1.1
    [FPGA.PcbDoc, FPGA.PrjPCB, FPGA1394-BOM.xls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]
2015-01-19 Changes for Rev 1.2: changed J9 and added J10
    [FPGA.PcbDoc, FPGA.PrjPCB, S02.SchDoc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]
2015-01-19 Changed schematic sheets to show Rev 1.2; added GND silkscreen to J9.
    [FPGA.PcbDoc, S01.SchDoc, S02.SchDoc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]
2015-01-19 Update BOM for FPGA1394 Rev 1.2
    [FPGA1394-BOM.xls]
2015-01-19 Final changes for FPGA1394 Rev 1.2
    [FPGA.PcbDoc]
2015-01-19 Added PCB Fabrication (Gerbers) and Assembly for FPGA1394 Rev 1.2
2015-01-19 Added PDF of schematics for FPGA1394 Rev 1.2
2015-01-19 Corrected manufacturer part number for D5-8 in BOM.
    [FPGA1394-BOM.xls]
2015-01-19 BOM: Changed oscillators U10, U11 from AVX/Kyocera to KC5032A series due to product obsolescence; changed oscillator U12 from AVX/Kyocera 29.4989MHz to Abracon 14.7456MHz due to better part availabil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
    [FPGA1394-BOM.xls]
2015-01-19 Updated BOM to indicate that U12 (29.4989MHz oscillator) is now "Do Not Install".
    [FPGA1394-BOM.xls]
2015-02-18 Rev1.3 design (see README.md)
    [FPGA.PcbDoc, FPGA.PrjPCB, FPGA1394-BOM.xls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]
2015-02-19 Changed specified finish from HASL to ENIG (previous boards used ENIG anyway); updated README.md to include change to U2 footprint
    [FPGA.PcbDoc]
2015-02-20 Added note 3 to BOM
    [FPGA1394-BOM.xls]
2015-02-20 Removed erroneous note about unused C39 from schematics
    [S01.SchDoc]
2015-03-02 Changed internal layers from 2 oz to 1 oz copper
    [FPGA.PcbDoc]
2015-12-09 FPGA Rev 2.0 (added Ethernet)
    [FPGA.PcbDoc, FPGA.PrjPCB, FPGA1394-BOM.xls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]
2015-12-09 Rev 2.1 changes; no BOM changes except for blank PCB
    [FPGA.PcbDoc, FPGA.PrjPCB, FPGA1394-BOM.xls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]
2016-03-16 Added note about alternate part for U5-6
    [FPGA1394-BOM.xls]
2016-09-23 Added J9 (6-pin header)
    [FPGA1394-BOM.xls]
2018-07-06 Added alternate part numbers for Q3 and Q7 (notes 4, 5); used for Build 6
    [FPGA1394-BOM.xls]
2020-02-06 Changed P/N for U5-6 and Q4-6 due to obsolescence; provided alternate P/N for CN1-6; still Rev 2.1
    [FPGA1394-BOM.xls]
2021-11-04 Update P/N for 25MHz crystal; minor change for 24.576MHz crystal
    [FPGA1394-BOM.xls]
2021-11-11 Added all Avcom P/N to BOM
    [FPGA1394-BOM.xls]
2021-11-13 Added alternate parts to BOM (see notes 7-9)
    [FPGA1394-BOM.xls]
2022-02-14 Alternate source for Firewire connector (J3-4)
    [FPGA1394-BOM.xls]
